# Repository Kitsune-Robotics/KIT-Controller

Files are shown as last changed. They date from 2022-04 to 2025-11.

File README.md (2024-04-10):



# KIT-Controller

Hardware for the KIT Controller

Migrated from https://kitsunehosting.net/gitea/Kenwood/lewis-crawler

# Getting Started

## Clone this repo

```shell
git clone https://github.com/Kitsune-Robotics/KIT-Controller.git --recurse-submodules
```

You will *need* the submodules as all of the boards in `Hardware` have several library dependencies.

`Hardware/BackPlane` Contains the backplane for the system, the backplane connects all other cards together.
`Hardware/KIT_Controller` Is the main processing unit of the system, the core computer where this code (will eventually) live
`Hardware/Dev_Card` Is a development tool, made to be slotted into any slot and connected via probes, solder jumpers and wires to aid in developing/debugging

You can re-initalize/update submodules by using the command

```shell
git submodule update --init --recursive
```

## 3D Models

Some libraries (namely my own `kenwoodfox-kicad-libraries` lib) requires setting a path variable to show some 3d models.

Follow the instructions inside of these libraries folders for how to set these paths.

# Parts

The kit controller and its other boards use the Sullins [EBM15DSEH](https://www.digikey.com/en/products/detail/sullins-connector-solutions/EBM15DSEH/927297) to connect to the backplane.

Its a little expensive, in the future the [WingTAT ED30MEBGFBK ](https://www.lcsc.com/product-detail/Card-Edge-Connectors_WingTAT-ED30MEBGFBK_C5242012.html) is a possible replacement.

## Project Layout

If you want to use this project template for yourself, you can find it [here!](https://github.com/KenwoodFox/Project-Template)

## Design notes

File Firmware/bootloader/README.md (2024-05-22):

# Custom in-between bootloader (and flashing)

I was very inspired by usedbytes and his custom bootloader, 
for now I've just forked the serial bootloader he made. But
with this base I hope to allow for loading of firmware via my custom SPI
interface (possibly via radio!)

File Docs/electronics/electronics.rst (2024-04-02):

Electronics
###########

Schematics
==========



Renders
=======



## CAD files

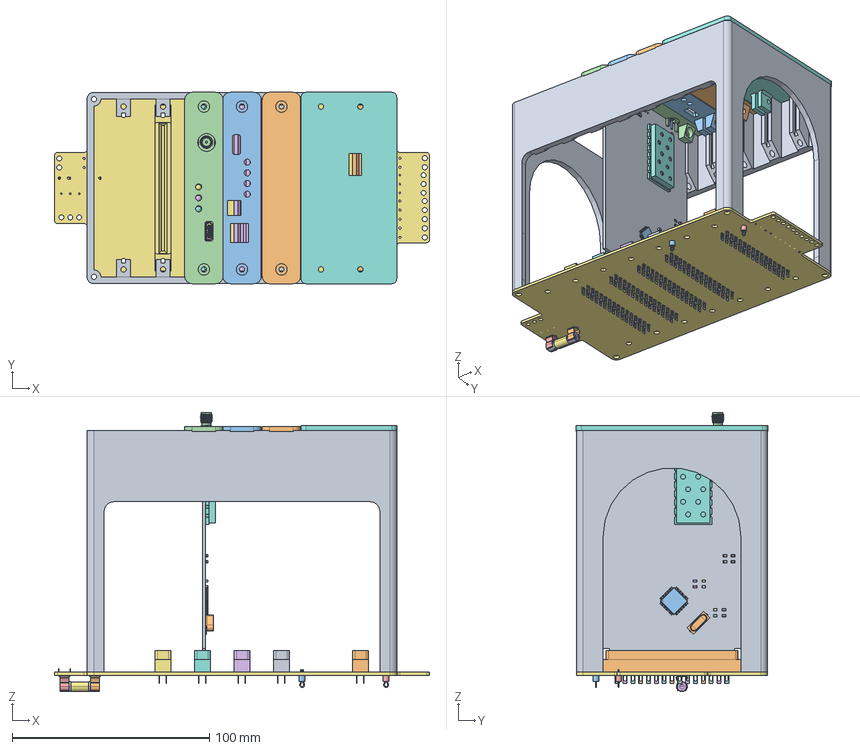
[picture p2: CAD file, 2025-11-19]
Hardware/BackPlane/CAD/Rails.FCStd
190.0 x 97.0 x 141.5 mm
Rail Body
Blank End
Fennec End
tmpe4ztpdd5 PCB
EBM15DSEH005
EBM15DSEH006
EBM15DSEH007
EBM15DSEH008
EBM15DSEH009
EBM15DSEH010
EBM15DSEH011
EBM15DSEH012
EBM15DSEH013
EBM15DSEH014
EBM15DSEH015
EBM15DSEH016
EBM15DSEH017
EBM15DSEH018
EBM15DSEH019
EBM15DSEH020
EBM15DSEH021
EBM15DSEH022
EBM15DSEH023
EBM15DSEH024
EBM15DSEH025
EBM15DSEH026
EBM15DSEH027
EBM15DSEH028
EBM15DSEH029
EBM15DSEH030
EBM15DSEH031
EBM15DSEH032
EBM15DSEH033
EBM15DSEH034
EBM15DSEH035
EBM15DSEH038
EBM15DSEH039
EBM15DSEH040
EBM15DSEH041
EBM15DSEH042
EBM15DSEH043
EBM15DSEH044
EBM15DSEH045
EBM15DSEH046
EBM15DSEH047
EBM15DSEH048
EBM15DSEH049
EBM15DSEH050
EBM15DSEH051
EBM15DSEH052
EBM15DSEH053
EBM15DSEH054
EBM15DSEH055
EBM15DSEH056
EBM15DSEH057
EBM15DSEH058
EBM15DSEH059
EBM15DSEH060
EBM15DSEH061
EBM15DSEH062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

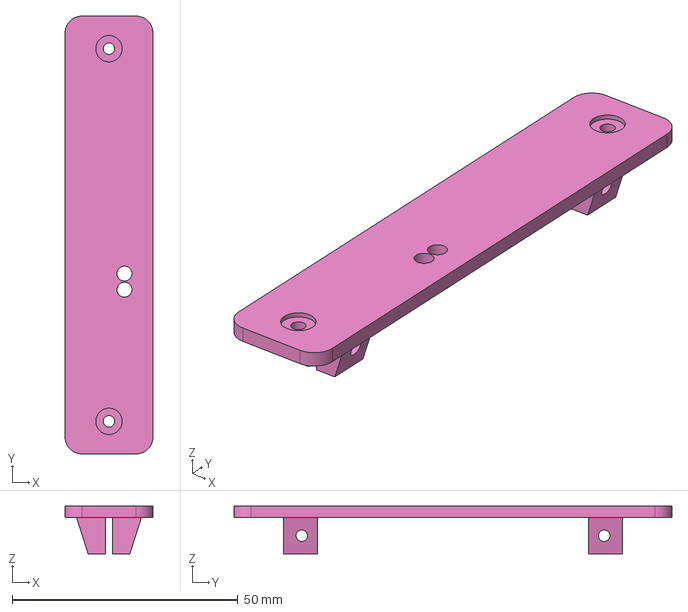
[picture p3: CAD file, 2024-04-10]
Hardware/Dev_Card/CAD/Faceplate-Dev Card End.step
19.5 x 97.0 x 10.5 mm

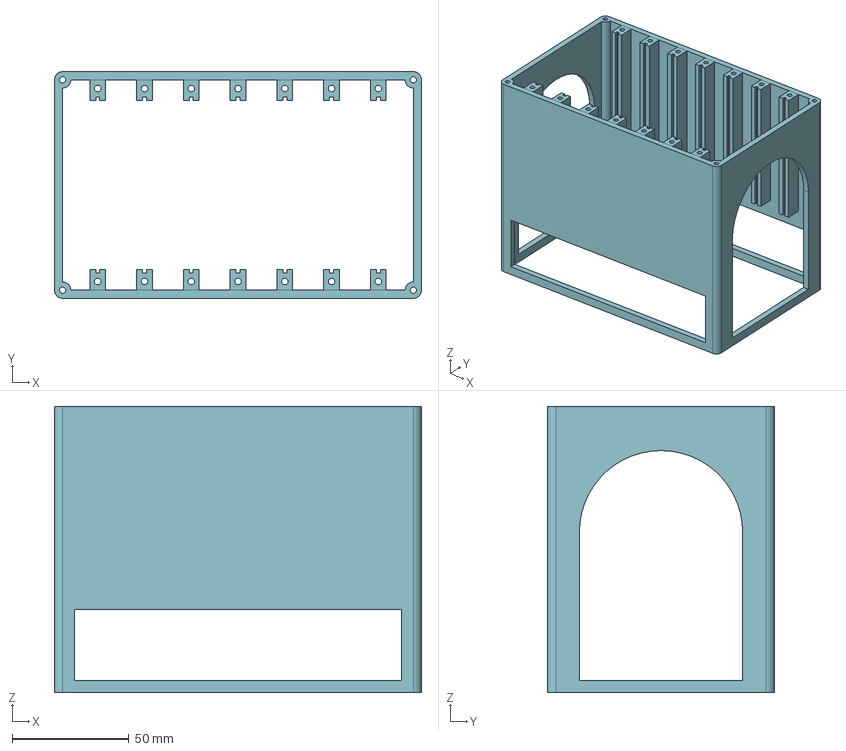
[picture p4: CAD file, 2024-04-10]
Hardware/BackPlane/CAD/Rails-Rail Body.step
157.0 x 97.0 x 122.4 mm

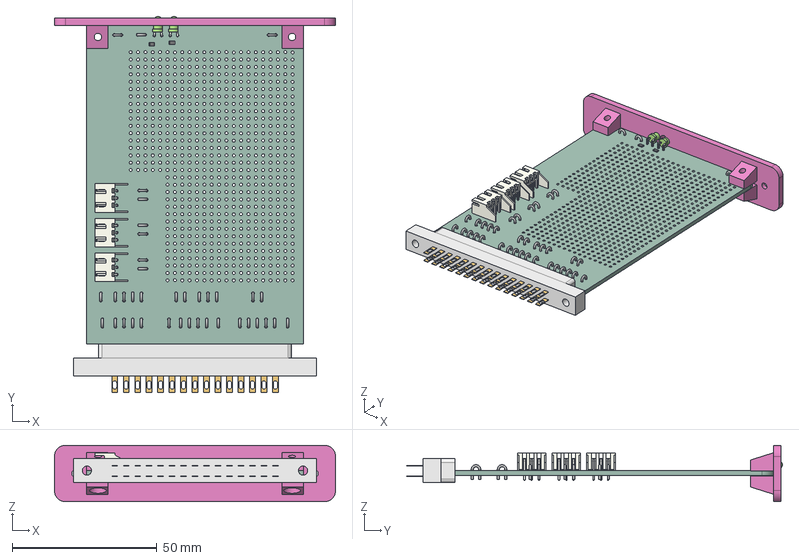
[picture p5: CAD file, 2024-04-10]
Hardware/BackPlane/CAD/Dev_Card-3D.step
97.0 x 129.8 x 19.5 mm
TestPoint_Bridge_Pitch2.54mm_Drill1.0mm x 38
EBM15DSEH
Dev Card End
R_0805_2012Metric x 2
JST_S3B_XH_A_1 x 3
LED_D3.0mm_Horizontal_O1.27mm_Z2.0mm x 2
tmp2yx70o5x_PCB

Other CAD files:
Hardware/KIT_Controller/CAD/Faceplate-Kit Controller End.step
Hardware/Dev_Card/CAD/Faceplate.FCStd
Hardware/KIT_Controller/CAD/Faceplate.FCStd
Hardware/BackPlane/CAD/Rails-Blank End.step

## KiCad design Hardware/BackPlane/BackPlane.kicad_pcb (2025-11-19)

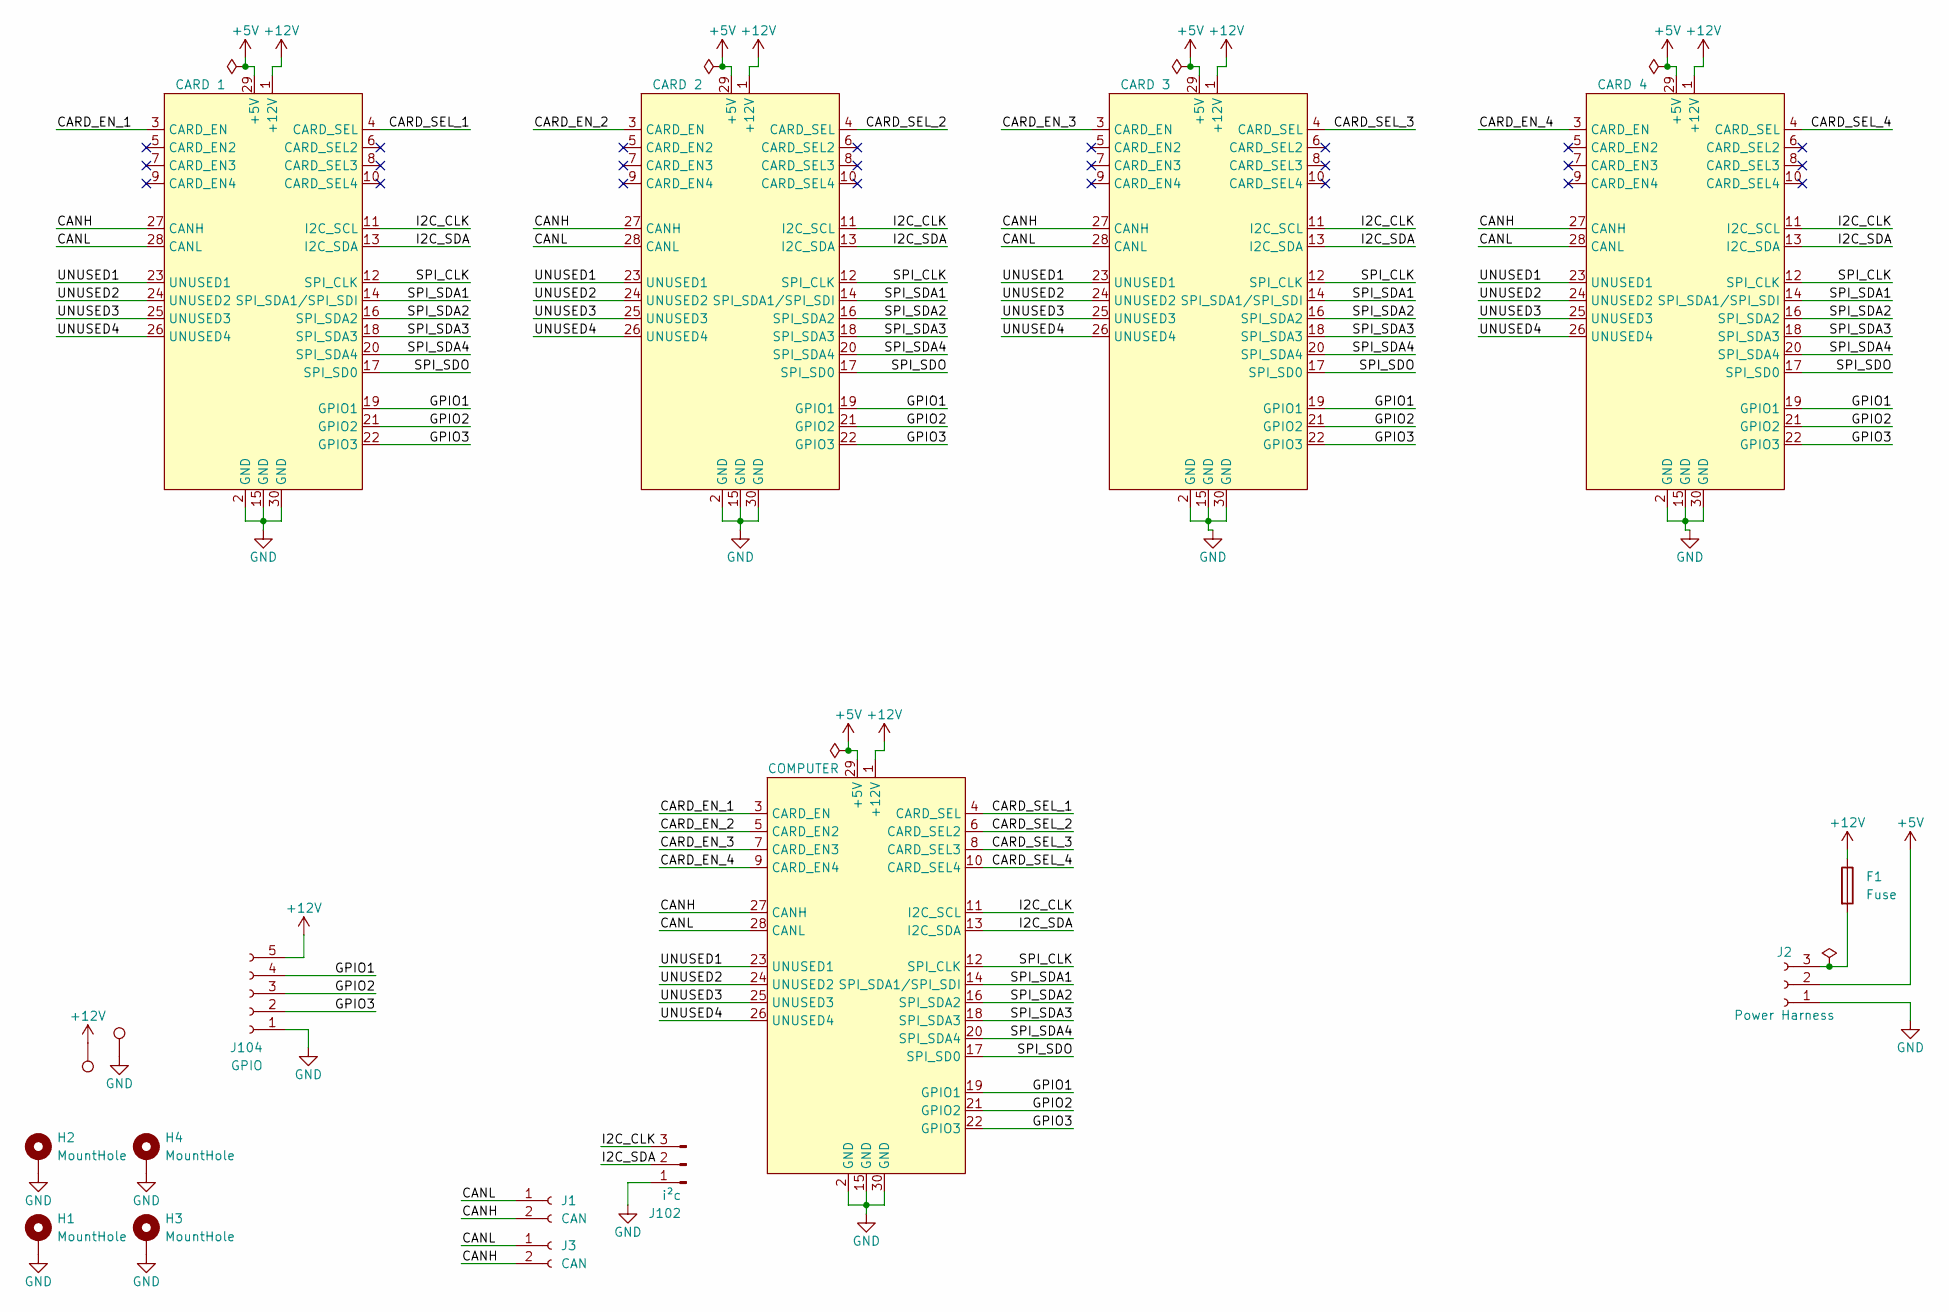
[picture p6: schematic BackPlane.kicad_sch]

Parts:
F1: Fuse; Fuseholder_Littelfuse_100_series_5x20mm; LCSC# C3130
H1, H2, H3, H4: MountHole; MountingHole_3.5mm_Pad
J1, J3: CAN; SolderWire-0.5sqmm_1x02_P4.6mm_D0.9mm_OD2.1mm_Relief
J2: Power Harness; SolderWire-0.25sqmm_1x03_P4.5mm_D0.65mm_OD2mm_Relief
J102: i²c; SolderWire-0.25sqmm_1x03_P4.5mm_D0.65mm_OD2mm_Relief
J104: GPIO; SolderWire-0.5sqmm_1x05_P4.6mm_D0.9mm_OD2.1mm_Relief
TP101, TP102: TestPoint; TestPoint_Loop_D2.54mm_Drill1.5mm_Beaded
U101: COMPUTER; EBM15DSEH
U102: CARD 1; EBM15DSEH
U103: CARD 2; EBM15DSEH
U104: CARD 3; EBM15DSEH
U105: CARD 4; EBM15DSEH

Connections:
+5V: J2.2, U101.29 (+5V), U102.29 (+5V), U103.29 (+5V), U104.29 (+5V), U105.29 (+5V)
+12V: F1.1, J104.5, TP101.1, U101.1 (+12V), U102.1 (+12V), U103.1 (+12V), U104.1 (+12V), U105.1 (+12V)
/CANH: J1.2, J3.2, U101.27 (CANH), U102.27 (CANH), U103.27 (CANH), U104.27 (CANH), U105.27 (CANH)
/CANL: J1.1, J3.1, U101.28 (CANL), U102.28 (CANL), U103.28 (CANL), U104.28 (CANL), U105.28 (CANL)
/CARD_EN_1: U101.3 (CARD_EN), U102.3 (CARD_EN)
/CARD_EN_2: U101.5 (CARD_EN2), U103.3 (CARD_EN)
/CARD_EN_3: U101.7 (CARD_EN3), U104.3 (CARD_EN)
/CARD_EN_4: U101.9 (CARD_EN4), U105.3 (CARD_EN)
/CARD_SEL_1: U101.4 (CARD_SEL), U102.4 (CARD_SEL)
/CARD_SEL_2: U101.6 (CARD_SEL2), U103.4 (CARD_SEL)
/CARD_SEL_3: U101.8 (CARD_SEL3), U104.4 (CARD_SEL)
/CARD_SEL_4: U101.10 (CARD_SEL4), U105.4 (CARD_SEL)
/GPIO1: J104.4, U101.19 (GPIO1), U102.19 (GPIO1), U103.19 (GPIO1), U104.19 (GPIO1), U105.19 (GPIO1)
/GPIO2: J104.3, U101.21 (GPIO2), U102.21 (GPIO2), U103.21 (GPIO2), U104.21 (GPIO2), U105.21 (GPIO2)
/GPIO3: J104.2, U101.22 (GPIO3), U102.22 (GPIO3), U103.22 (GPIO3), U104.22 (GPIO3), U105.22 (GPIO3)
/I2C_CLK: J102.3, U101.11 (I2C_SCL), U102.11 (I2C_SCL), U103.11 (I2C_SCL), U104.11 (I2C_SCL), U105.11 (I2C_SCL)
/I2C_SDA: J102.2, U101.13 (I2C_SDA), U102.13 (I2C_SDA), U103.13 (I2C_SDA), U104.13 (I2C_SDA), U105.13 (I2C_SDA)
/SPI_CLK: U101.12 (SPI_CLK), U102.12 (SPI_CLK), U103.12 (SPI_CLK), U104.12 (SPI_CLK), U105.12 (SPI_CLK)
/SPI_SDA1: U101.14 (SPI_SDA1/SPI_SDI), U102.14 (SPI_SDA1/SPI_SDI), U103.14 (SPI_SDA1/SPI_SDI), U104.14 (SPI_SDA1/SPI_SDI), U105.14 (SPI_SDA1/SPI_SDI)
/SPI_SDA2: U101.16 (SPI_SDA2), U102.16 (SPI_SDA2), U103.16 (SPI_SDA2), U104.16 (SPI_SDA2), U105.16 (SPI_SDA2)
/SPI_SDA3: U101.18 (SPI_SDA3), U102.18 (SPI_SDA3), U103.18 (SPI_SDA3), U104.18 (SPI_SDA3), U105.18 (SPI_SDA3)
/SPI_SDA4: U101.20 (SPI_SDA4), U102.20 (SPI_SDA4), U103.20 (SPI_SDA4), U104.20 (SPI_SDA4), U105.20 (SPI_SDA4)
/SPI_SDO: U101.17 (SPI_SD0), U102.17 (SPI_SD0), U103.17 (SPI_SD0), U104.17 (SPI_SD0), U105.17 (SPI_SD0)
/UNUSED1: U101.23 (UNUSED1), U102.23 (UNUSED1), U103.23 (UNUSED1), U104.23 (UNUSED1), U105.23 (UNUSED1)
/UNUSED2: U101.24 (UNUSED2), U102.24 (UNUSED2), U103.24 (UNUSED2), U104.24 (UNUSED2), U105.24 (UNUSED2)
/UNUSED3: U101.25 (UNUSED3), U102.25 (UNUSED3), U103.25 (UNUSED3), U104.25 (UNUSED3), U105.25 (UNUSED3)
/UNUSED4: U101.26 (UNUSED4), U102.26 (UNUSED4), U103.26 (UNUSED4), U104.26 (UNUSED4), U105.26 (UNUSED4)
GND: H1.1, H2.1, H3.1, H4.1, J2.1, J102.1, J104.1, TP102.1, U101.2 (GND), U101.15 (GND), U101.30 (GND), U102.2 (GND), U102.15 (GND), U102.30 (GND), U103.2 (GND), U103.15 (GND), U103.30 (GND), U104.2 (GND), U104.15 (GND), U104.30 (GND), U105.2 (GND), U105.15 (GND), U105.30 (GND)
unnamed: F1.2, J2.3

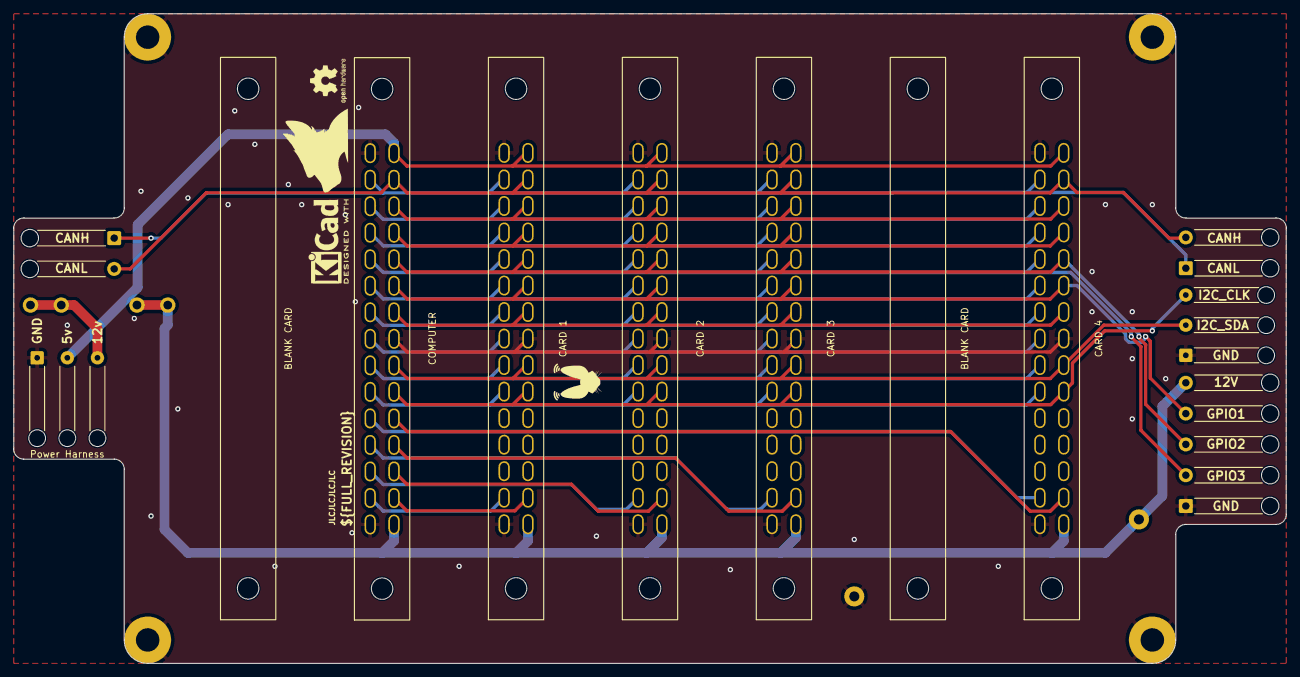
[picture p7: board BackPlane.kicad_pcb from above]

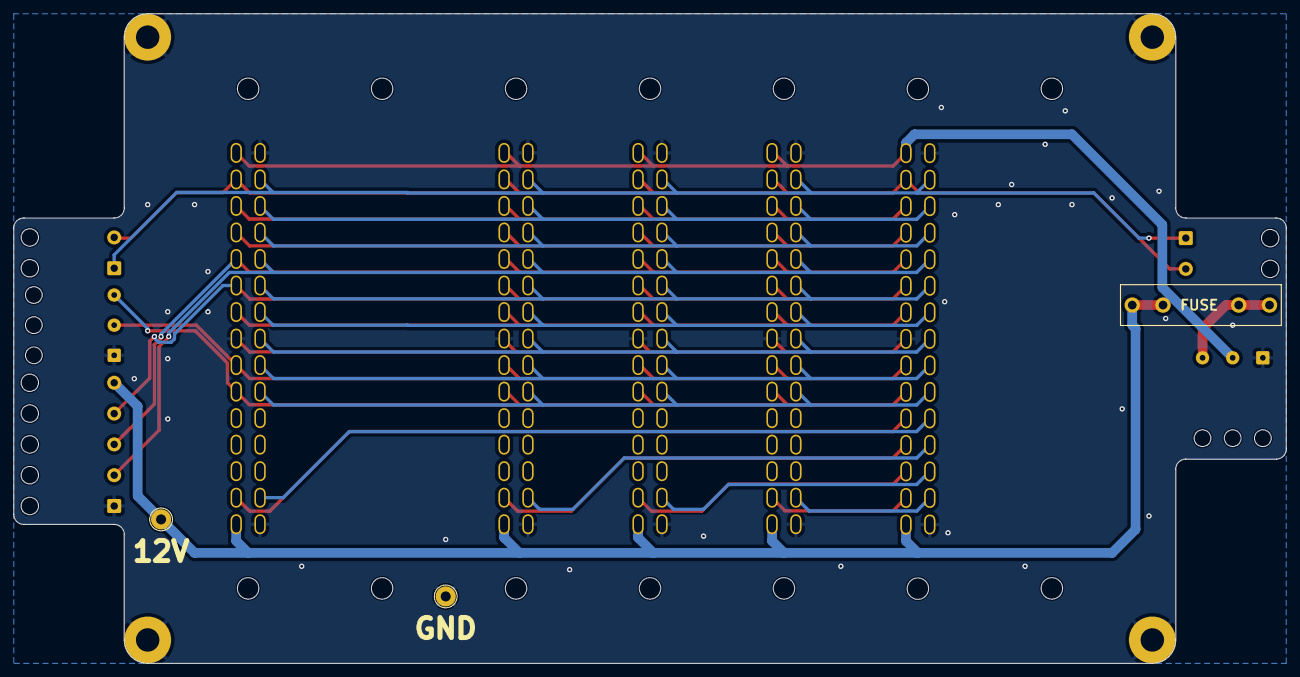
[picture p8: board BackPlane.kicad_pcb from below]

Board: 2 copper layers, 190.0 x 97.0 mm, 23 parts (3 on the bottom side), 29 nets.

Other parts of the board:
BLANK1, BLANK2: EBM15DSEH; EBM15DSEH_Blank
LOGO1: LOGO; KITSUNE_LOGO
LOGO2: LOGO; fennec_logo_solid_small
LOGO3: OSHW-Logo2_7.3x6mm_SilkScreen
LOGO5: KiCad-Logo2_5mm_SilkScreen

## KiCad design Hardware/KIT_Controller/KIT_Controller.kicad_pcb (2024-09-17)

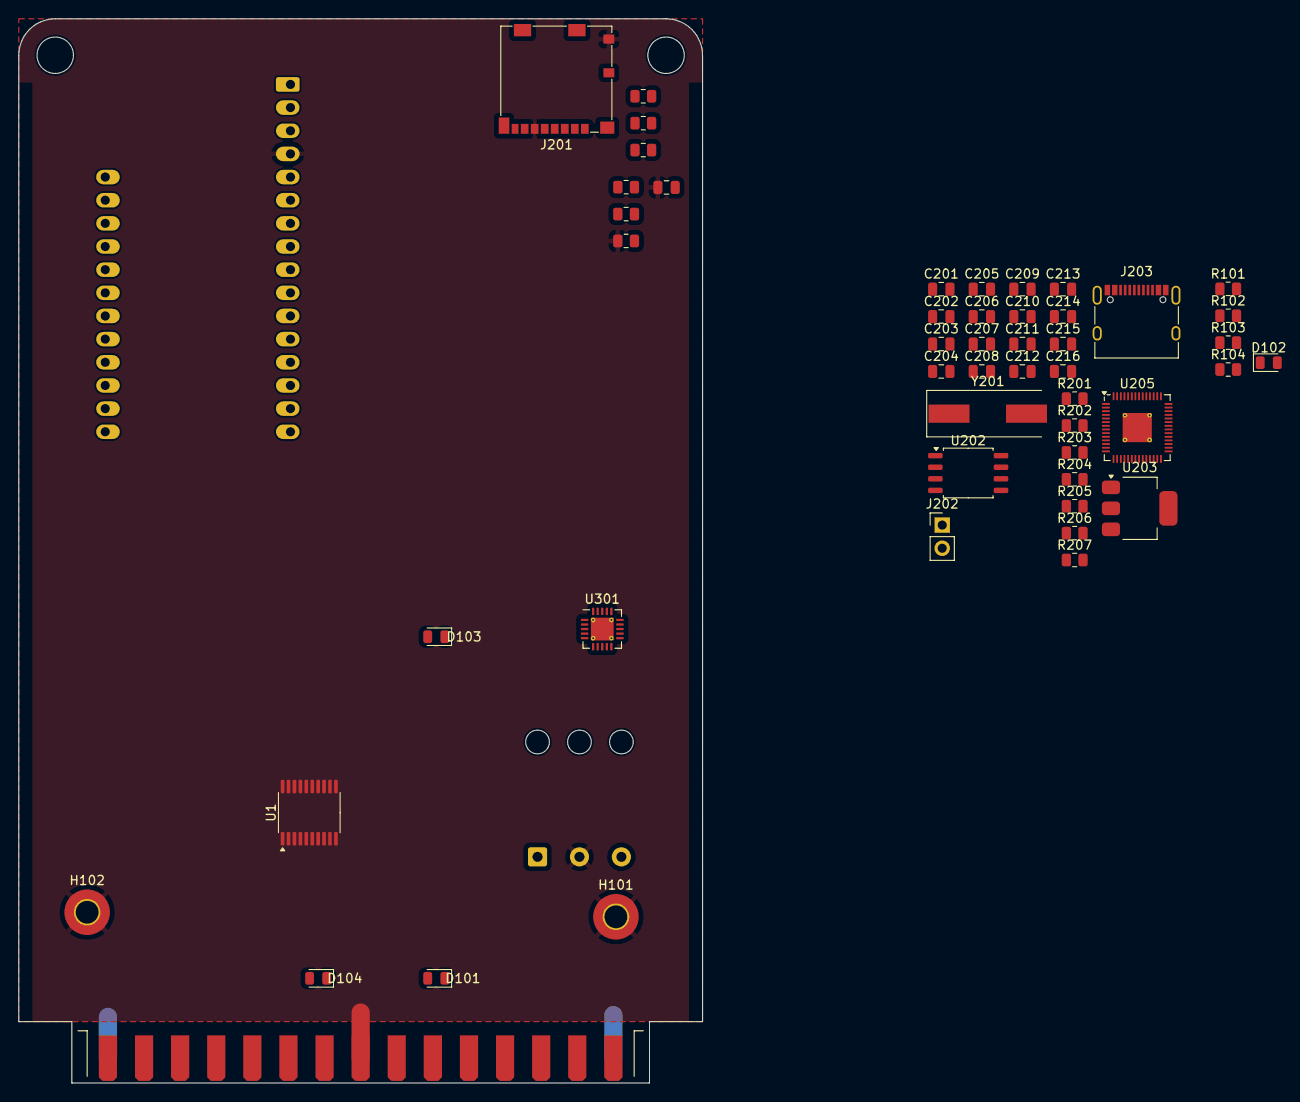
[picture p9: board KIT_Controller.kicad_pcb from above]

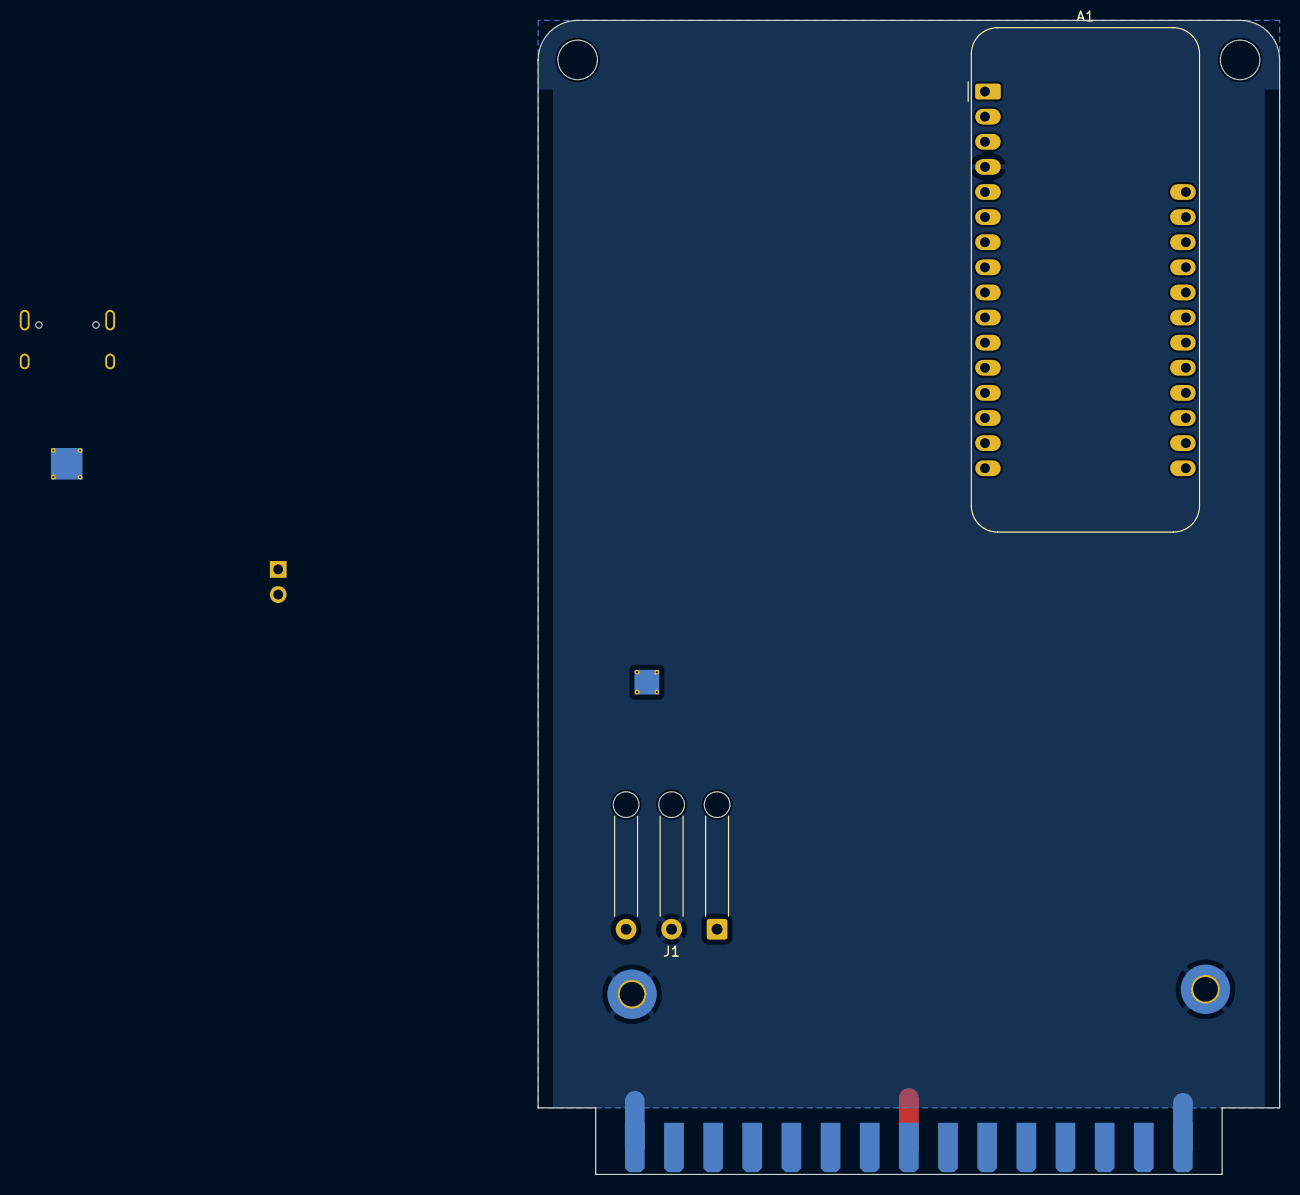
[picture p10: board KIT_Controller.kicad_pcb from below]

Board: 2 copper layers, 75.0 x 116.7 mm, 52 parts (2 on the bottom side), 33 nets.

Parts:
A1: Adafruit_Feather_Generic; Adafruit_Feather
C201, C202: 27p; C_0805_2012Metric
C203, C205, C217: 10u; C_0805_2012Metric
C204, C207, C208, C209, C210, C211, C212, C213, C214, C215: 100n; C_0805_2012Metric
C206, C216: 1u; C_0805_2012Metric
D101: BL1; LED_0805_2012Metric
D102: BL2; LED_0805_2012Metric
D103: BL3; LED_0805_2012Metric
D104: BL4; LED_0805_2012Metric
H101, H102: MountingHole_Pad; MountingHole_2.5mm_Pad_TopBottom
J1: CAN; SolderWire-0.5sqmm_1x03_P4.6mm_D0.9mm_OD2.1mm_Relief
J201: Micro_SD_Card_Det1; microSD_HC_Molex_104031-0811
J202: USB_BOOT; PinHeader_1x02_P2.54mm_Vertical
J203: USBC; USB_C_Receptacle_XKB_U262-16XN-4BVC11
R101, R102, R103, R104: 450; R_0805_2012Metric
R201, R203: 1k; R_0805_2012Metric
R202, R215, R216, R217: DNP; R_0805_2012Metric
R204, R205: 27; R_0805_2012Metric
R206, R207: 5K1; R_0805_2012Metric
R208, R209: 10K; R_0805_2012Metric
R210: DNF; R_0805_2012Metric
U1: TXB0108PW; TSSOP-20_4.4x6.5mm_P0.65mm
U102: CARD ?; Lewis_Card_Connector
U202: W25Q128JVS; SOIC-8_5.23x5.23mm_P1.27mm
U203: NCP1117-3.3_SOT223; SOT-223-3_TabPin2
U205: RP2040; QFN-56-1EP_7x7mm_P0.4mm_EP3.2x3.2mm_ThermalVias
U301: CC1101; QFN-20-1EP_4x4mm_P0.5mm_EP2.5x2.5mm_ThermalVias
Y201: Crystal; Crystal_SMD_HC49-SD

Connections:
+1V1: C206.2, C207.2, C208.2, U205.23 (DVDD), U205.45 (VREG_VOUT), U205.50 (DVDD)
+3.3V: C205.2, U203.2 (VO)
+3V3: A1.2 (3V3), C204.2, C209.2, C210.2, C211.2, C212.2, C213.2, C214.2, C215.2, C216.2, C217.2, D101.1 (K), D102.1 (K), D103.1 (K), D104.1 (K), J201.4 (VDD), R202.2, R208.2, R209.2, R215.2, R216.2, R217.2, U202.8 (VCC), U205.1 (IOVDD), U205.10 (IOVDD), U205.22 (IOVDD), U205.33 (IOVDD), U205.42 (IOVDD), U205.43 (ADC_AVDD), U205.44 (VREG_IN), U205.48 (USB_VDD), U205.49 (IOVDD)
/CANH: J1.3, U102.27 (CANH)
/CANL: J1.1, U102.28 (CANL)
/MCU/QSPI_SCLK: U202.6 (CLK), U205.52 (QSPI_SCLK)
/MCU/QSPI_SD0: U202.5 (DI(IO0)), U205.53 (QSPI_SD0)
/MCU/QSPI_SD1: U202.2 (DO(IO1)), U205.55 (QSPI_SD1)
/MCU/QSPI_SD2: U202.3 (IO2), U205.54 (QSPI_SD2)
/MCU/QSPI_SD3: U202.7 (IO3), U205.51 (QSPI_SD3)
/MCU/QSPI_SS: R201.2, R202.1, U202.1 (~CS), U205.56 (QSPI_SS)
/MCU/SD_CLK: J201.5 (CLK), R210.2, R217.1, U205.8 (GPIO6)
/MCU/SD_CMD: J201.3 (CMD), U205.31 (GPIO20)
/MCU/SD_DAT0: J201.7 (DAT0), R216.1, U205.32 (GPIO21)
/MCU/SD_DAT1: J201.8 (DAT1), R208.1, U205.34 (GPIO22)
/MCU/SD_DAT2: J201.1 (DAT2), R209.1, U205.35 (GPIO23)
/MCU/SD_DAT3: J201.2 (DAT3/CD), R215.1, U205.36 (GPIO24)
/MCU/USB+: J203.A6 (D+), J203.B6 (D+)
/MCU/USB-: J203.A7 (D-), J203.B7 (D-)
/MCU/XIN: C201.2, U205.20 (XIN), Y201.2
/MCU/XOUT: R203.2, U205.21 (XOUT)
GND: A1.4 (GND), C201.1, C202.1, C203.1, C204.1, C205.1, C206.1, C207.1, C208.1, C209.1, C210.1, C211.1, C212.1, C213.1, C214.1, C215.1, C216.1, C217.1, H101.1, H102.1, J1.2, J201.6 (VSS), J201.10 (SHIELD), J202.2, J203.A1 (GND), J203.A12 (GND), J203.B1 (GND), J203.B12 (GND), J203.S1 (SHIELD), R101.1, R102.1, R103.1, R104.1, R206.1, R207.1, R210.1, U102.2 (GND), U102.15 (GND), U102.30 (GND), U202.4 (GND), U203.1 (GND), U205.19 (TESTEN), U205.57 (GND)
unnamed: C202.2, R203.1, Y201.1
unnamed: D101.2 (A), R101.2
unnamed: D102.2 (A), R102.2
unnamed: D103.2 (A), R103.2
unnamed: D104.2 (A), R104.2
unnamed: J202.1, R201.1
unnamed: J203.A5 (CC1), R207.2
unnamed: J203.B5 (CC2), R206.2
unnamed: R205.1, U205.46 (USB_DM)
unnamed: R204.1, U205.47 (USB_DP)
VBUS: C203.2, J203.A4 (VBUS), J203.A9 (VBUS), J203.B4 (VBUS), J203.B9 (VBUS), U203.3 (VI)

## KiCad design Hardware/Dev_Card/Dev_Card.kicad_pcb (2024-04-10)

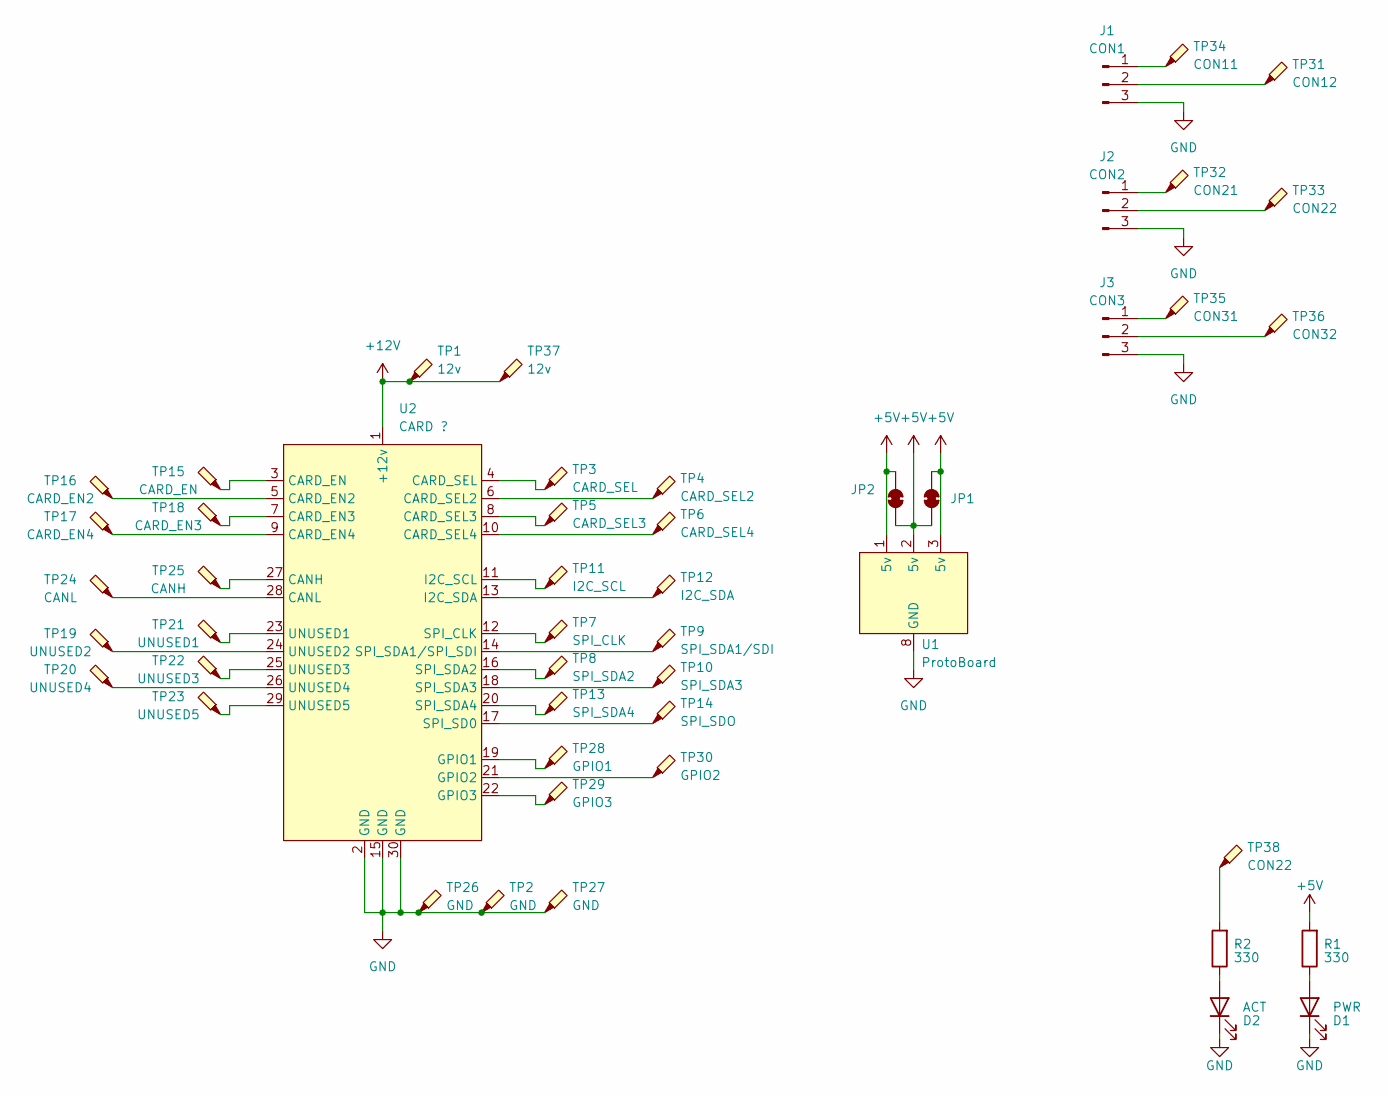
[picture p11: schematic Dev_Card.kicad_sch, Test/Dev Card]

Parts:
D1: PWR; LED_D3.0mm_Horizontal_O1.27mm_Z2.0mm
D2: ACT; LED_D3.0mm_Horizontal_O1.27mm_Z2.0mm
J1: CON1; JST_XH_S3B-XH-A-1_1x03_P2.50mm_Horizontal
J2: CON2; JST_XH_S3B-XH-A-1_1x03_P2.50mm_Horizontal
J3: CON3; JST_XH_S3B-XH-A-1_1x03_P2.50mm_Horizontal
JP1, JP2: SolderJumper_2_Bridged; SolderJumper-2_P1.3mm_Bridged_Pad1.0x1.5mm
R1, R2: 330; R_0805_2012Metric
TP1, TP37: 12v; TestPoint_Bridge_Pitch2.54mm_Drill1.0mm
TP2, TP26, TP27: GND; TestPoint_Bridge_Pitch2.54mm_Drill1.0mm
TP3: CARD_SEL; TestPoint_Bridge_Pitch2.54mm_Drill1.0mm
TP4: CARD_SEL2; TestPoint_Bridge_Pitch2.54mm_Drill1.0mm
TP5: CARD_SEL3; TestPoint_Bridge_Pitch2.54mm_Drill1.0mm
TP6: CARD_SEL4; TestPoint_Bridge_Pitch2.54mm_Drill1.0mm
TP7: SPI_CLK; TestPoint_Bridge_Pitch2.54mm_Drill1.0mm
TP8: SPI_SDA2; TestPoint_Bridge_Pitch2.54mm_Drill1.0mm
TP9: SPI_SDA1/SDI; TestPoint_Bridge_Pitch2.54mm_Drill1.0mm
TP10: SPI_SDA3; TestPoint_Bridge_Pitch2.54mm_Drill1.0mm
TP11: I2C_SCL; TestPoint_Bridge_Pitch2.54mm_Drill1.0mm
TP12: I2C_SDA; TestPoint_Bridge_Pitch2.54mm_Drill1.0mm
TP13: SPI_SDA4; TestPoint_Bridge_Pitch2.54mm_Drill1.0mm
TP14: SPI_SDO; TestPoint_Bridge_Pitch2.54mm_Drill1.0mm
TP15: CARD_EN; TestPoint_Bridge_Pitch2.54mm_Drill1.0mm
TP16: CARD_EN2; TestPoint_Bridge_Pitch2.54mm_Drill1.0mm
TP17: CARD_EN4; TestPoint_Bridge_Pitch2.54mm_Drill1.0mm
TP18: CARD_EN3; TestPoint_Bridge_Pitch2.54mm_Drill1.0mm
TP19: UNUSED2; TestPoint_Bridge_Pitch2.54mm_Drill1.0mm
TP20: UNUSED4; TestPoint_Bridge_Pitch2.54mm_Drill1.0mm
TP21: UNUSED1; TestPoint_Bridge_Pitch2.54mm_Drill1.0mm
TP22: UNUSED3; TestPoint_Bridge_Pitch2.54mm_Drill1.0mm
TP23: UNUSED5; TestPoint_Bridge_Pitch2.54mm_Drill1.0mm
TP24: CANL; TestPoint_Bridge_Pitch2.54mm_Drill1.0mm
TP25: CANH; TestPoint_Bridge_Pitch2.54mm_Drill1.0mm
TP28: GPIO1; TestPoint_Bridge_Pitch2.54mm_Drill1.0mm
TP29: GPIO3; TestPoint_Bridge_Pitch2.54mm_Drill1.0mm
TP30: GPIO2; TestPoint_Bridge_Pitch2.54mm_Drill1.0mm
TP31: CON12; TestPoint_Bridge_Pitch2.54mm_Drill1.0mm
TP32: CON21; TestPoint_Bridge_Pitch2.54mm_Drill1.0mm
TP33, TP38: CON22; TestPoint_Bridge_Pitch2.54mm_Drill1.0mm
TP34: CON11; TestPoint_Bridge_Pitch2.54mm_Drill1.0mm
TP35: CON31; TestPoint_Bridge_Pitch2.54mm_Drill1.0mm
TP36: CON32; TestPoint_Bridge_Pitch2.54mm_Drill1.0mm
U1: ProtoBoard; ProtoBoardLayout
U2: CARD ?; Lewis_Card_Connector

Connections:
+5V: JP1.1 (A), JP1.2 (B), JP2.1 (A), JP2.2 (B), R1.2, U1.1 (5v), U1.2 (5v), U1.3 (5v)
+12V: TP1.1, TP37.1, U2.1 (+12v)
GND: D1.1 (K), D2.1 (K), J1.3, J2.3, J3.3, TP2.1, TP26.1, TP27.1, U1.8 (GND), U2.2 (GND), U2.15 (GND), U2.30 (GND)
unnamed: D1.2 (A), R1.1
unnamed: D2.2 (A), R2.1
unnamed: J1.1, TP34.1
unnamed: J1.2, TP31.1
unnamed: J2.1, TP32.1
unnamed: J2.2, TP33.1
unnamed: J3.1, TP35.1
unnamed: J3.2, TP36.1
unnamed: R2.2, TP38.1
unnamed: TP25.1, U2.27 (CANH)
unnamed: TP24.1, U2.28 (CANL)
unnamed: TP16.1, U2.5 (CARD_EN2)
unnamed: TP18.1, U2.7 (CARD_EN3)
unnamed: TP17.1, U2.9 (CARD_EN4)
unnamed: TP15.1, U2.3 (CARD_EN)
unnamed: TP4.1, U2.6 (CARD_SEL2)
unnamed: TP5.1, U2.8 (CARD_SEL3)
unnamed: TP6.1, U2.10 (CARD_SEL4)
unnamed: TP3.1, U2.4 (CARD_SEL)
unnamed: TP28.1, U2.19 (GPIO1)
unnamed: TP30.1, U2.21 (GPIO2)
unnamed: TP29.1, U2.22 (GPIO3)
unnamed: TP11.1, U2.11 (I2C_SCL)
unnamed: TP12.1, U2.13 (I2C_SDA)
unnamed: TP7.1, U2.12 (SPI_CLK)
unnamed: TP14.1, U2.17 (SPI_SD0)
unnamed: TP9.1, U2.14 (SPI_SDA1/SPI_SDI)
unnamed: TP8.1, U2.16 (SPI_SDA2)
unnamed: TP10.1, U2.18 (SPI_SDA3)
unnamed: TP13.1, U2.20 (SPI_SDA4)
unnamed: TP21.1, U2.23 (UNUSED1)
unnamed: TP19.1, U2.24 (UNUSED2)
unnamed: TP22.1, U2.25 (UNUSED3)
unnamed: TP20.1, U2.26 (UNUSED4)
unnamed: TP23.1, U2.29 (UNUSED5)

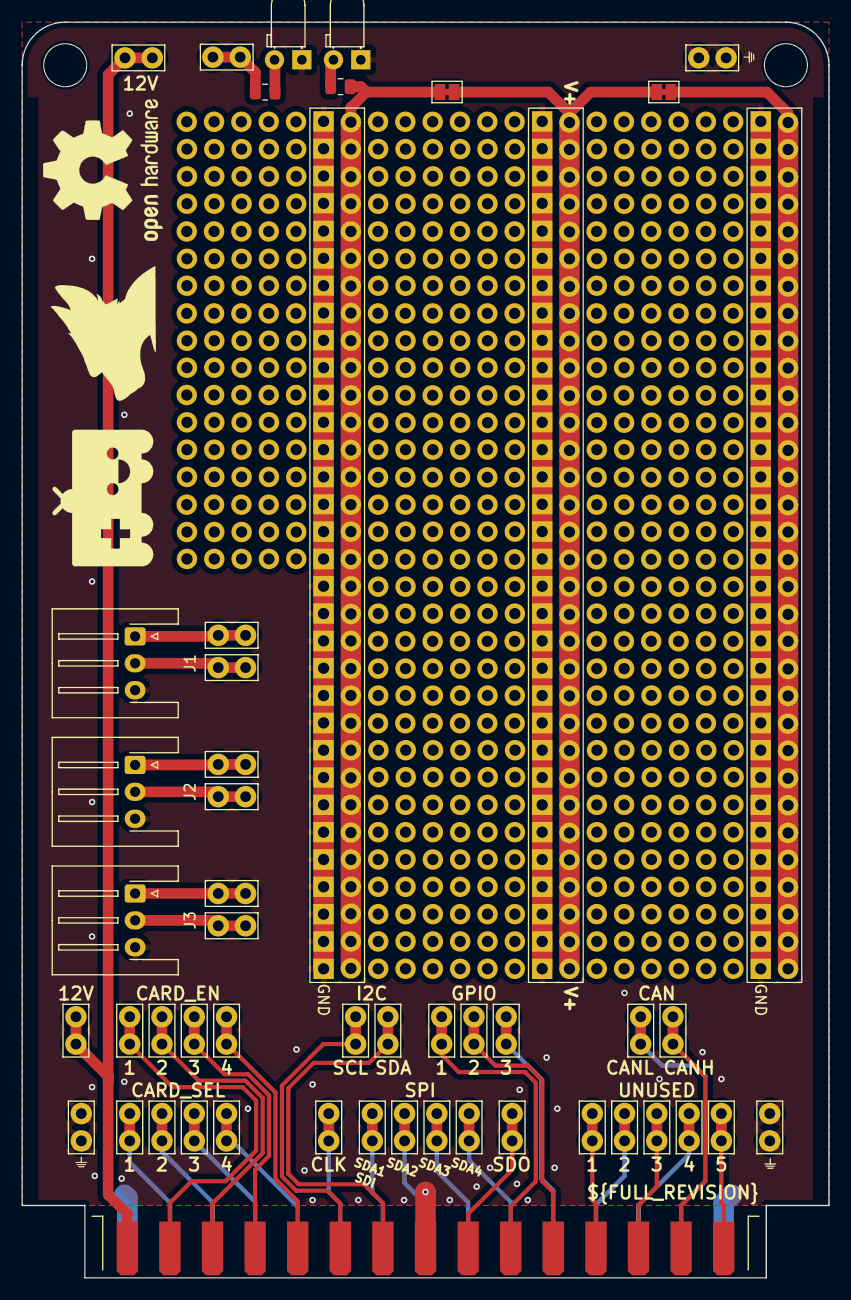
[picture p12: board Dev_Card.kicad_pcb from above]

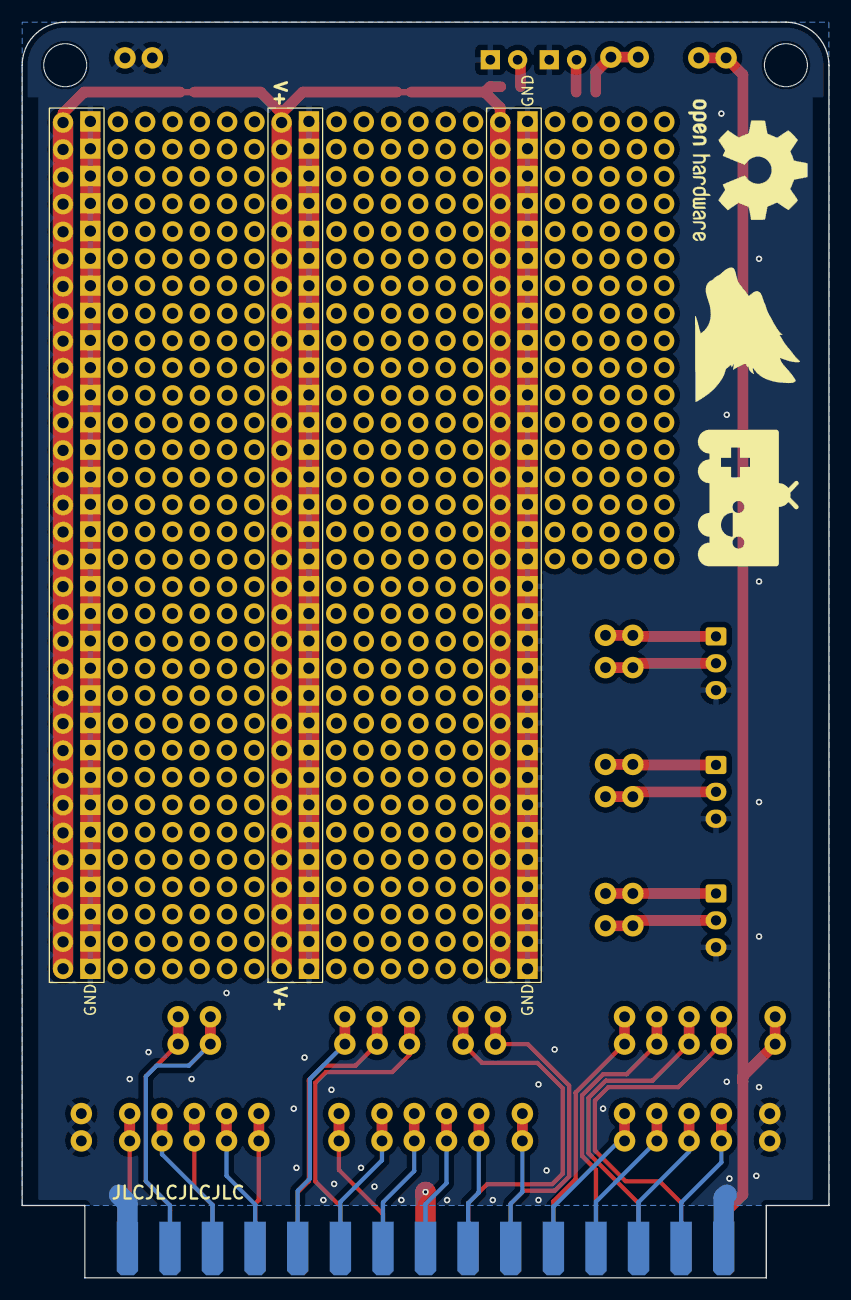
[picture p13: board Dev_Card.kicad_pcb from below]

Board: 2 copper layers, 75.0 x 116.7 mm, 55 parts (3 on the bottom side), 38 nets.

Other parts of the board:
LOGO1, LOGO1#2: LOGO; ROBOTSTREAMER_LOGO
LOGO2, LOGO2#2: LOGO; KITSUNE_LOGO
LOGO3, LOGO3#2: OSHW-Logo2_14.6x12mm_SilkScreen

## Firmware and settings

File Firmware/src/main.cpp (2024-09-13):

/* Raspberry Pi */
#include <stdio.h>
#include "pico/stdlib.h"

/* FreeRTOS */
#include "FreeRTOS.h"
#include "task.h"
#include "queue.h"

// Our own
#include "pindefs.h"
#include "local_queues.h"
#include "console.h"            // Parent data for all consoles
#include "usb_console.h"        // USB serial console
#include "command_dispatcher.h" // Functions for dispatching commands
#include "led_task.h"           // Manages LED functions
#include "can_controller.h"     // Manages the canbus

// Global Definitions
QueueHandle_t cmdQueue = NULL;

int main()
{
    // From pico SDK, init all
    stdio_init_all();

    // FreeRTOS Create queues
    cmdQueue = xQueueCreate(4, sizeof(uint));

    // Check if the queue was created successfully
    if (cmdQueue == NULL)
    {
        // Handle error
        printf("There was an error creating the cmdQueue");
    }

    // FreeRTOS Create tasks
    xTaskCreate(led_task, "LED_Task", 256, NULL, 1, NULL);
    xTaskCreate(can_task, "CAN_Task", 512, NULL, 1, NULL);
    xTaskCreate(commandDispatcherTask, "CmdDispatcher", 512, NULL, 1, NULL);
    xTaskCreate(usb_console, "USB_Console", 1024, NULL, 1, NULL);

    // Begin scheduler
    vTaskStartScheduler();

    while (true)
    {
        // Main task can never exit
    };
}

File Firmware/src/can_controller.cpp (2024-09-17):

#include "can_controller.h"
#include "pico/stdlib.h"
#include "console.h"
#include "mcp2515.h"
#include "can.h"

// Constants for the CAN controller (We get these from the adafruit feather we're using)
const uint8_t CAN_QUEUE_LENGTH = 10;
const uint8_t CS_PIN = 19;          // Chip Select (CS) pin for the SPI
const uint8_t TX_PIN = 15;          // MOSI pin for SPI communication (TX)
const uint8_t RX_PIN = 8;           // MISO pin for SPI communication (RX)
const uint8_t SCK_PIN = 14;         // Clock pin for SPI communication (SCK)
const uint32_t SPI_CLOCK = 1000000; // 1 MHz SPI clock

// SPI instance for the MCP2515
spi_inst_t *spi_channel = spi0; // Use spi0 or spi1 based on your board

static QueueHandle_t canQueue;                                                // RTOS queue for CAN commands
static MCP2515 can0(spi_channel, CS_PIN, TX_PIN, RX_PIN, SCK_PIN, SPI_CLOCK); // Proper MCP2515 instance

struct can_frame rx;

// Function to request status info from the MCP2515
void request_can_status(Command_t *cmd)
{
    if (canQueue == NULL)
    {
        return;
    }

    uint8_t statusCommand = CAN_COMMAND_GET_STATUS;
    xQueueSend(canQueue, &statusCommand, 0);
}

// Function to send a CAN frame
void send_can_frame(Command_t *cmd)
{
    if (canQueue == NULL)
    {
        return;
    }

    uint8_t sendFrameCommand = CAN_COMMAND_SEND_FRAME;
    xQueueSend(canQueue, &sendFrameCommand, 0);
}

// Function to initialize CAN communication
void setup_can()
{
    // Initialize MCP2515 interface
    can0.reset();
    can0.setBitrate(CAN_500KBPS, MCP_16MHZ); // Use 500Kbps, typical for many setups
    can0.setNormalMode();
}

// The CAN task function
void can_task(void *pvParams)
{
    uint8_t canCommand;                                // The general command to observe
    TickType_t lastWakeTime;                           // The last time we got a general command that wasn't idle
    const TickType_t tickInterval = pdMS_TO_TICKS(10); // 10 ms interval for checking commands

    // Setup CAN communication
    setup_can();

    // Create the CAN command queue
    canQueue = xQueueCreate(CAN_QUEUE_LENGTH, sizeof(uint8_t));
    if (canQueue == NULL)
    {
        console_printf(BROADCAST, "Failed to create CAN command queue.\n");
        vTaskDelete(NULL); // Delete the task if the queue creation fails
    }

    // Initialize the last wake time for accurate timing
    lastWakeTime = xTaskGetTickCount();

    while (true)
    {
        // Check for new commands in the queue
        if (xQueueReceive(canQueue, &canCommand, 0) == pdPASS)
        {
            if (canCommand == CAN_COMMAND_GET_STATUS)
            {
                // Retrieve the MCP2515 status
                uint8_t status = can0.getStatus();
                console_printf(BROADCAST, "MCP2515 Status: 0x%x\n", status);
            }
            else if (canCommand == CAN_COMMAND_SEND_FRAME)
            {
                // Send a simple CAN frame
                struct can_frame txFrame;
                txFrame.can_id = 0x123; // Example CAN ID
                txFrame.can_dlc = 2;    // Data length (2 bytes)
                txFrame.data[0] = 0xDE; // First byte of data
                txFrame.data[1] = 0xAD; // Second byte of data

                if (can0.sendMessage(&txFrame) == MCP2515::ERROR_OK)
                {
                    console_printf(BROADCAST, "CAN frame sent successfully!\n");
                }
                else
                {
                    console_printf(BROADCAST, "Failed to send CAN frame.\n");
                }
            }
        }

        // Wait for the next cycle with a short interval to remain responsive
        vTaskDelayUntil(&lastWakeTime, tickInterval);
    }
}

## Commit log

2022-04-12 import from feat/motor_mounts
    [9gServo.FCStd, Digi Case Base.FCStd, Digi Case Lid.FCStd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]
2022-04-22 Bump CAD
    [gearbox-outer-mount.FCStd, lewis-crawler.FCStd]
2022-04-28 move everything
    [axle-mounting-plate.FCStd, drivetrain-assembly.FCStd, gearbox-inner-mount.FCStd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]
2022-04-28 Fixup new everything
    [axle-mounting-plate.FCStd, drivetrain-assembly.FCStd, gearbox-mount.FCStd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]
2022-04-28 make encoder holder
    [encoder-holder.FCStd, encoder-spacer.FCStd]
2022-04-28 Clean encoder holder
    [encoder-holder.FCStd]
2022-04-29 Fixup cad and assy
    [drivetrain-assembly.FCStd, encoder-holder.FCStd, encoder-spacer.FCStd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]
2022-04-29 Boilerplate PCB sketch
    [LC-Mainboard.bak.kicad_sch]
2022-04-29 Add lib depend, remove bak and boilerplate
    [LC-Mainboard.kicad_pcb, LC-Mainboard.kicad_sch]
2022-04-29 Update all
    [LC-Mainboard.kicad_pcb, LC-Mainboard.kicad_sch]
2022-04-29 Fix encoder spacer, bump lib and implement max3232 in sch
    [LC-Mainboard.kicad_pcb, LC-Mainboard.kicad_sch, encoder-spacer.FCStd]
2022-04-30 Crawler Hardware (#1)
    This boilerplates all the hardware, a new branch should be made for producing a v0.1
    [LC-Mainboard.kicad_pcb, LC-Mainboard.kicad_sch]
2022-05-04 Make a v1.0 hardware release (#2)
    [LC-Mainboard.kicad_pcb, LC-Mainboard.kicad_sch]
2022-05-05 Update master assy
    [Frame.FCStd, drivetrain-assembly.FCStd, lewis-crawler.FCStd]
2022-05-05 Import v0.1 mainboard
    [Electrical Plate.FCStd, Frame.FCStd, lewis-crawler.FCStd]
2022-05-09 Bump kicad libs
2022-05-19 Bump kicad
2024-04-02 Remove all CAD
    [9gServo.FCStd, Digi Case Base.FCStd, Digi Case Lid.FCStd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]
2024-04-02 Remove simulation
    [model.sdf]
2024-04-02 Everything New (#8)
    [Faceplate-Kit Controller End.step, Faceplate.FCStd, KIT_Controller.kicad_pcb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]
2024-04-10 v1.1 Prototype (#11)
    [BackPlane.kicad_pcb, BackPlane.kicad_sch, Dev_Card-3D.step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]
2024-04-10 New branch for next board
    [KIT_Controller.kicad_pcb, KIT_Controller.kicad_sch]
2024-05-08 modified rails
    [Rails.FCStd]
2024-05-08 builtinLED is 13 on dev board
2024-06-04 Early prototype for usb_console, works pretty well :
2024-06-04 Break everything up (and prototype foxtool)
2024-06-04 Queue still has issues but its getting somewhere!
    [main.cpp]
2024-07-30 Create new 3d model for the prototype fontplate
    It has some issues tho, hole dosnt line up. you had one job joe!
    [Rails.FCStd]
2024-09-03 New tools and firmware!
    [Rails.FCStd]
2024-09-03 Very advacned led blinker
2024-09-13 Bump pico mcp lib and configure all
2024-09-17 Bump pcb and can_controller
    [KIT_Controller.kicad_pcb, KIT_Controller.kicad_sch, mcu.kicad_sch]
2025-11-19 Backplane now calls UNUSED5 5v offically
    [BackPlane.kicad_pcb, BackPlane.kicad_sch, Rails.FCStd]
